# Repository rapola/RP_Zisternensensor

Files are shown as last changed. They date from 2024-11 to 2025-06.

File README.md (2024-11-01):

# RP_Zisternensensor
Wasser-Füllstandsensor für Zisternen
 * ## Hauptplatine für Auswertung und MQTT Sender
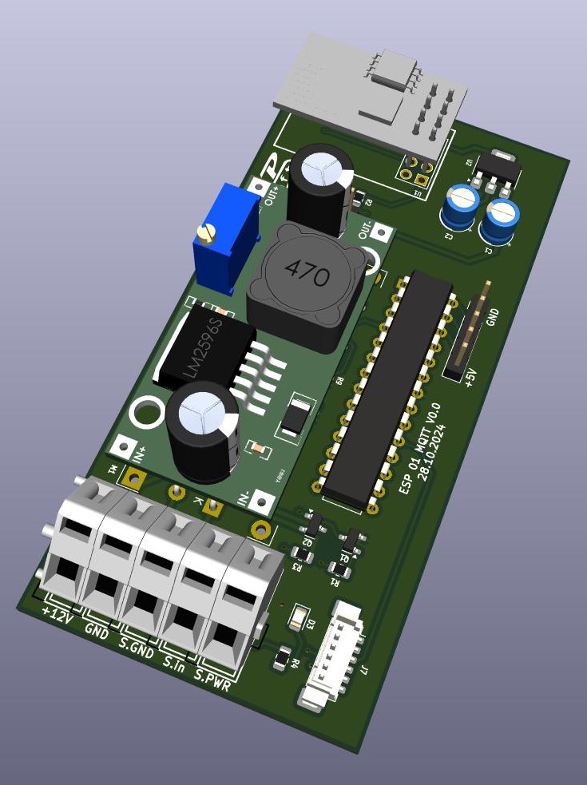
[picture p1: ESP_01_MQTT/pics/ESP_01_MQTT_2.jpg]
 
  <br>
  
  * ## Level Sensor:
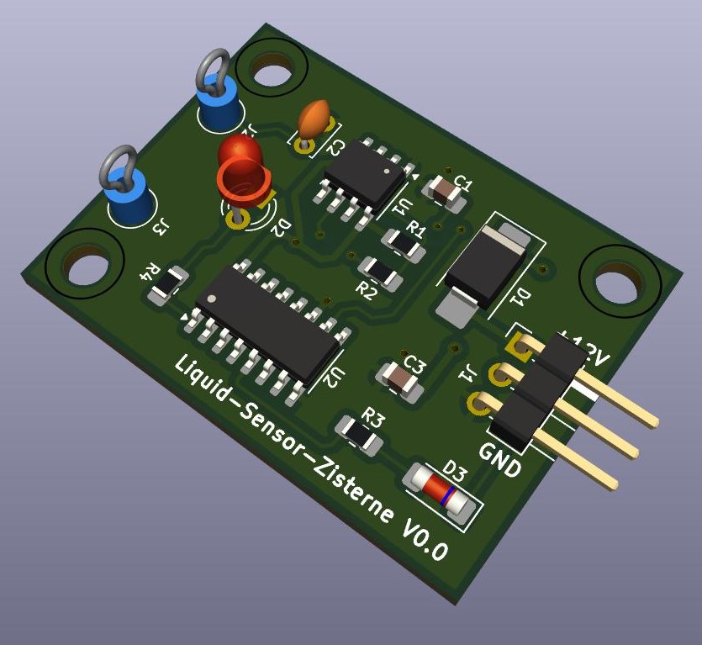
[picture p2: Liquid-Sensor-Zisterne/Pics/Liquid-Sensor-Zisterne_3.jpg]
  
  <br>

  ---
    
### Schematic

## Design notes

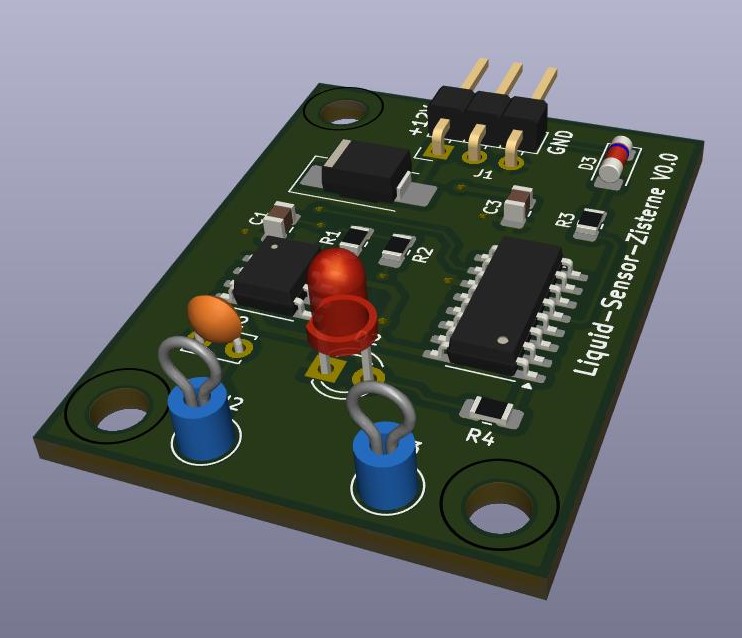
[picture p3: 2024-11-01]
Liquid-Sensor-Zisterne/Pics/Liquid-Sensor-Zisterne_2.jpg

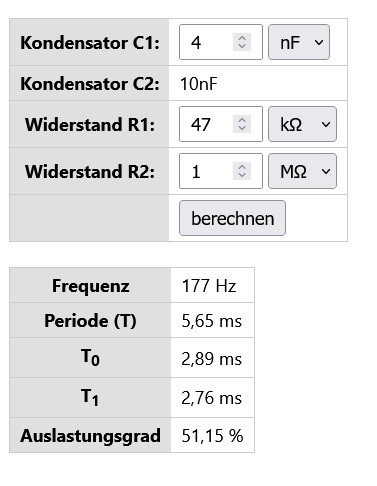
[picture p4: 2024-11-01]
Liquid-Sensor-Zisterne/Pics/NE555-4nf.jpg

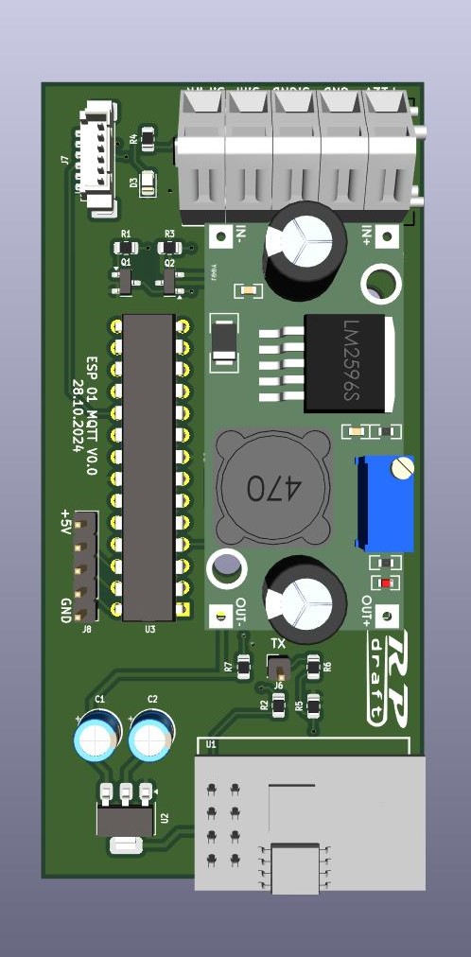
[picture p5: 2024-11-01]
ESP_01_MQTT/pics/ESP_01_MQTT_1.jpg

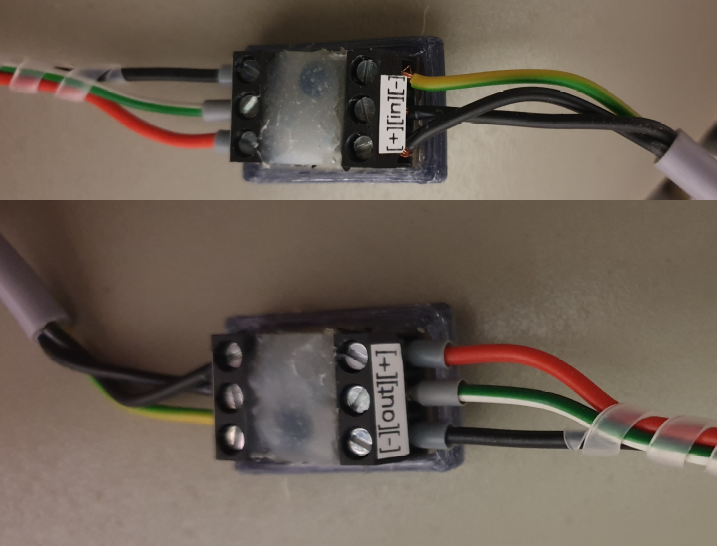
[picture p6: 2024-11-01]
Liquid-Sensor-Zisterne/Pics/Transistor-Stufe.png

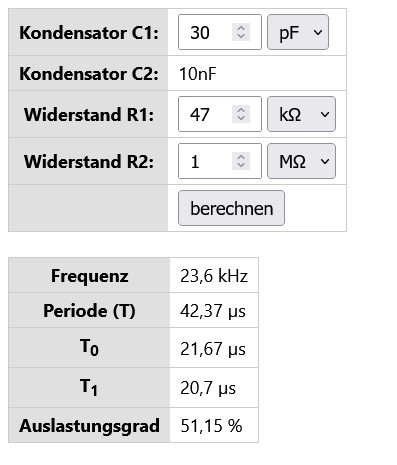
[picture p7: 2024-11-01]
Liquid-Sensor-Zisterne/Pics/NE555-30pf.jpg

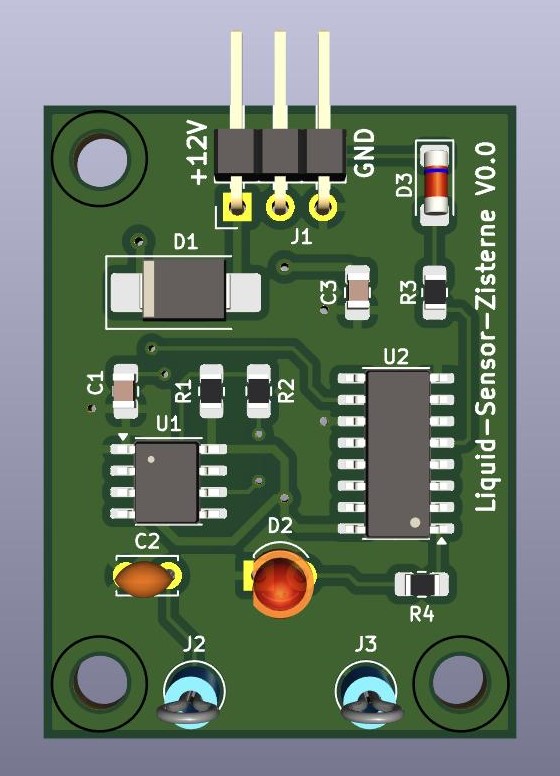
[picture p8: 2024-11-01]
Liquid-Sensor-Zisterne/Pics/Liquid-Sensor-Zisterne_1.jpg

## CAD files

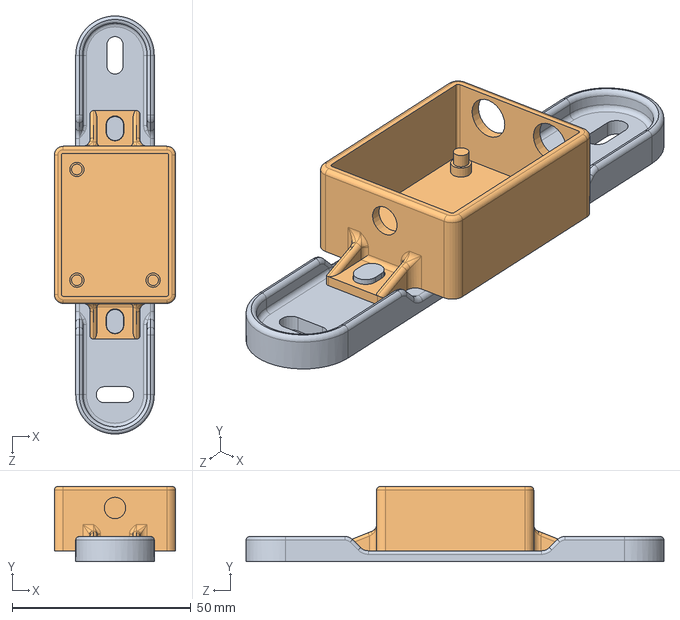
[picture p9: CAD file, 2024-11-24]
Liquid-Sensor-Zisterne/3D-Druck-Box/MBG-Sensor_01.SLDASM
34.0 x 21.0 x 117.0 mm
Vergussgeh_01
Adapter_95mm_Lochabstand

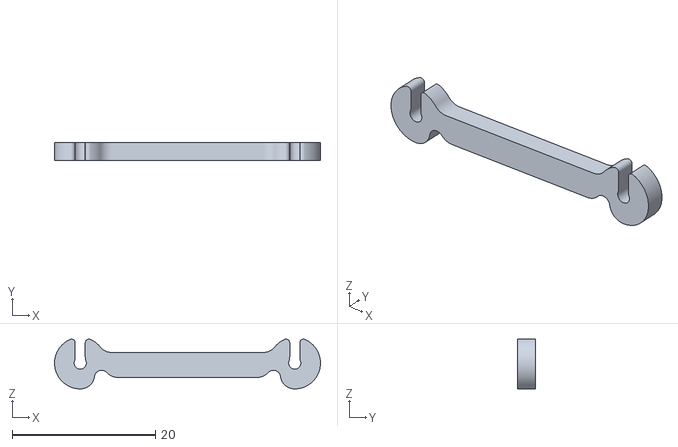
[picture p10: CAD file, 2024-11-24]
Liquid-Sensor-Zisterne/Abstandhalter_Kabel/Sensor-Abstandshalter_1.7-1.4-30.STL
37.2 x 2.50 x 6.96

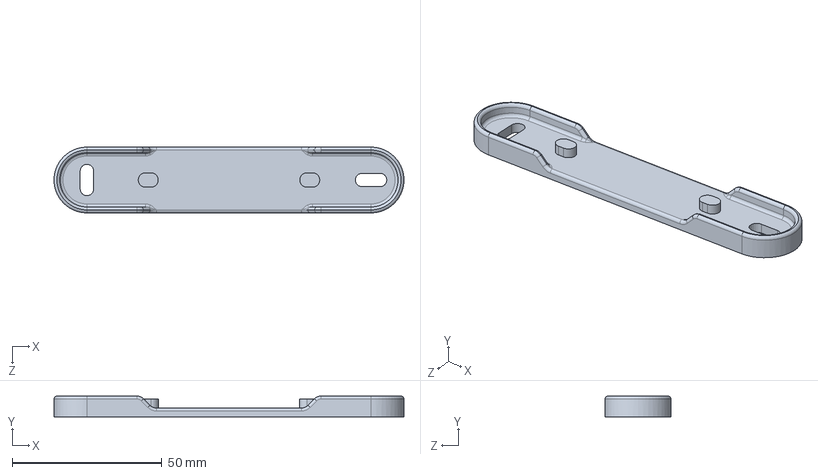
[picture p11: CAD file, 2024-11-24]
Liquid-Sensor-Zisterne/3D-Druck-Box/Adapter_95mm_Lochabstand.SLDPRT
117.0 x 7.00 x 22.0 mm

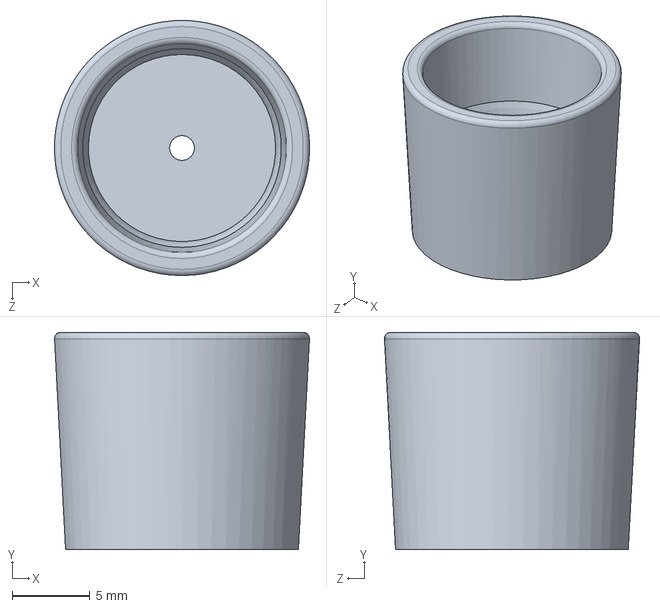
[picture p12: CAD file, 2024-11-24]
Liquid-Sensor-Zisterne/Abstandhalter_Kabel/Kabelende_Siegeltopf.SLDPRT
16.4 x 14.0 x 16.4 mm

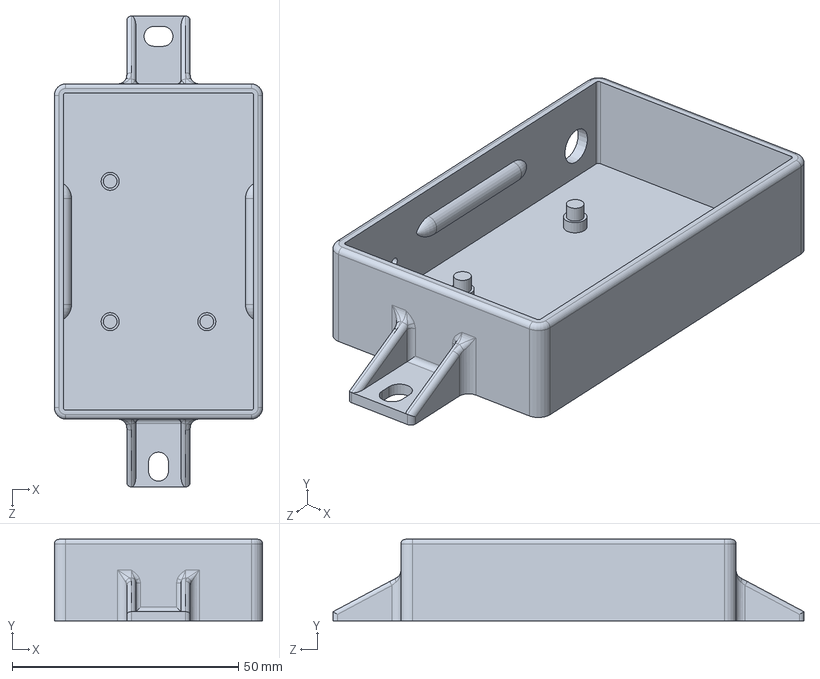
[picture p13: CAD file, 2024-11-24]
Liquid-Sensor-Zisterne/3D-Druck-Box/Vergussgeh_02.SLDPRT
46.0 x 18.0 x 104.0 mm

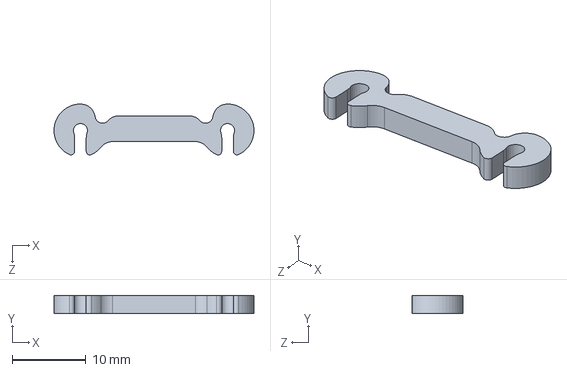
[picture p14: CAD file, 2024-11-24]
Liquid-Sensor-Zisterne/Abstandhalter_Kabel/Sensor-Abstandshalter.SLDPRT
27.2 x 2.50 x 6.92 mm

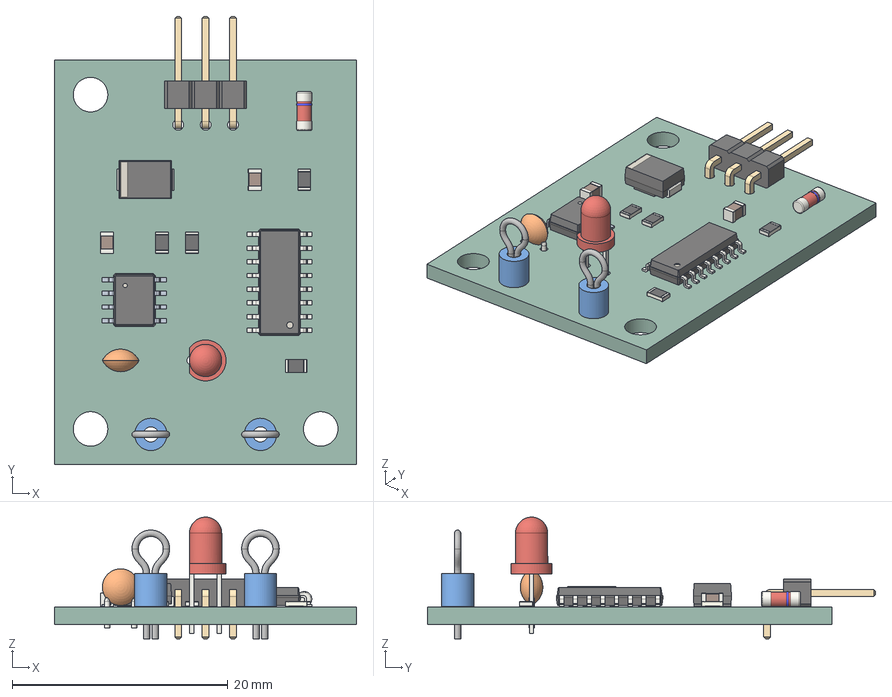
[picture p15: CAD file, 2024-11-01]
Liquid-Sensor-Zisterne/3D-Druck-Box/Liquid-Sensor-Zisterne.step
28.0 x 41.5 x 11.3 mm
R_0805_2012Metric x 4
D_MiniMELF_Standard
TestPoint_Loop_D3_50mm_Drill1_4mm_Beaded_cp x 2
C_0805_2012Metric x 2
D_SMB
PinHeader_1x03_P254mm_Horizontal
LED_D3.0mm
SOIC_16_39x99mm_P127mm
C_Disc_D34mm_W21mm_P250mm
CQ assembly
_autosave-Liquid-Sensor-Zisterne_PCB

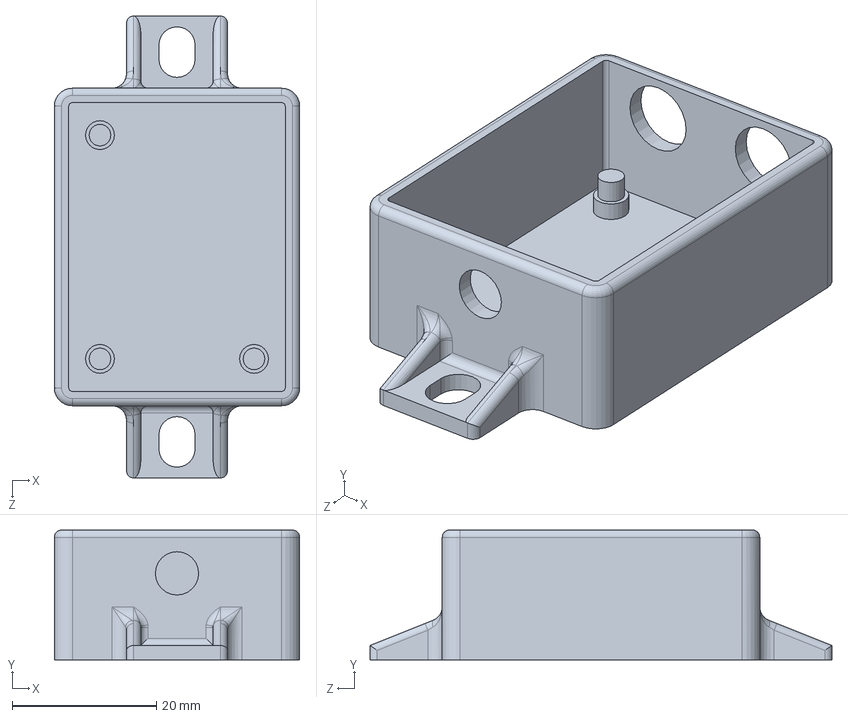
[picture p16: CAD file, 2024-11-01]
Liquid-Sensor-Zisterne/3D-Druck-Box/Vergussgeh_01.SLDPRT
34.0 x 18.0 x 64.0 mm

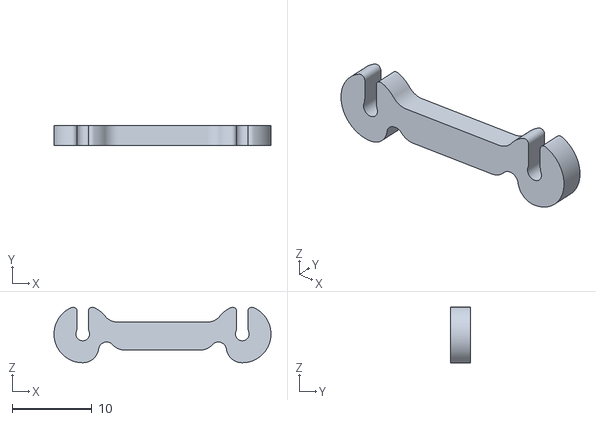
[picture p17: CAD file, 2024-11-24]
Liquid-Sensor-Zisterne/Abstandhalter_Kabel/Sensor-Abstandshalter_1.7-1.4-20.STL
27.2 x 2.50 x 6.96

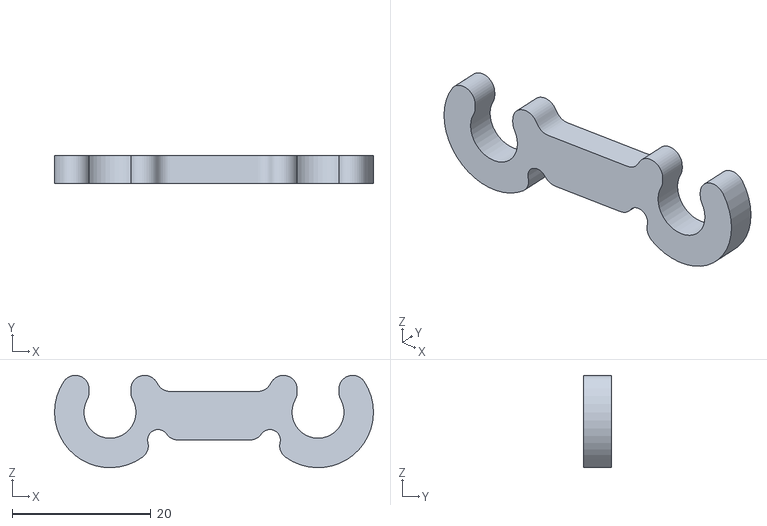
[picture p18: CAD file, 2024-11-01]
Liquid-Sensor-Zisterne/Abstandhalter_Kabel/Sensor-Abstandshalter_7.5-6-30.STL
46.0 x 4.00 x 13.3

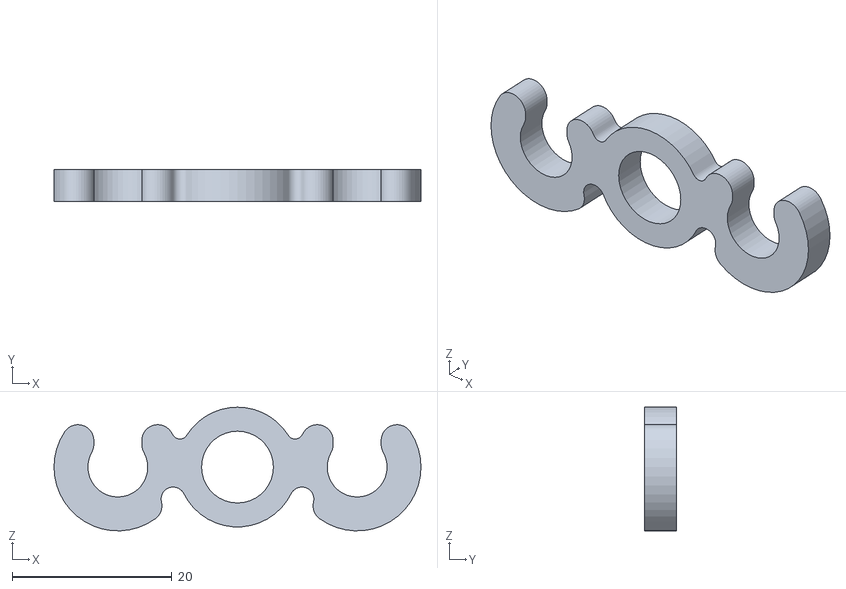
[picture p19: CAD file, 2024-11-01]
Liquid-Sensor-Zisterne/Abstandhalter_Kabel/Sensor-Abstandshalter_7.5-6-30_unten.STL
46.0 x 4.00 x 15.5

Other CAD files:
Liquid-Sensor-Zisterne/Abstandhalter_Kabel/Sensor-Abstandshalter_1.8-1.5-20.STL
Liquid-Sensor-Zisterne/3D-Druck-Box/Liquid-Sensor-Zisterne.SLDPRT
Liquid-Sensor-Zisterne/3D-Druck-Box/Vergussgeh_01.STL
Liquid-Sensor-Zisterne/Abstandhalter_Kabel/Kabelende_Siegeltopf.STL

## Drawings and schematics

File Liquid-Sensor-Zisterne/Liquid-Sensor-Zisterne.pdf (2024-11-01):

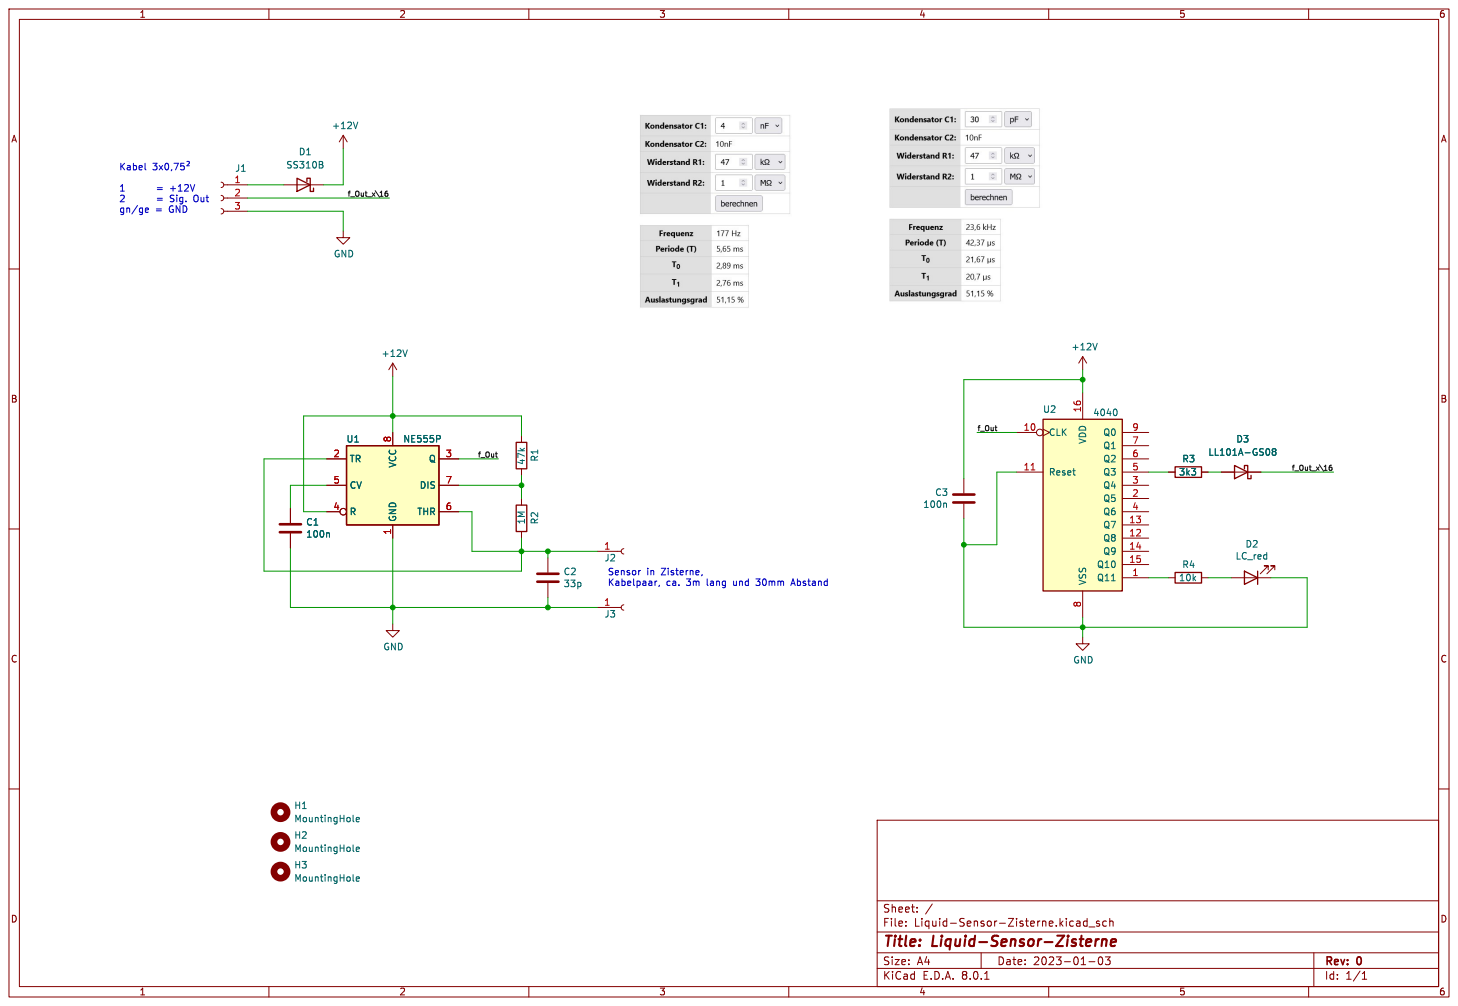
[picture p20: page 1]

File: Liquid-Sensor-Zisterne.kicad_sch Sheet: /
Id: 1/1 Title: Liquid-Sensor-Zisterne

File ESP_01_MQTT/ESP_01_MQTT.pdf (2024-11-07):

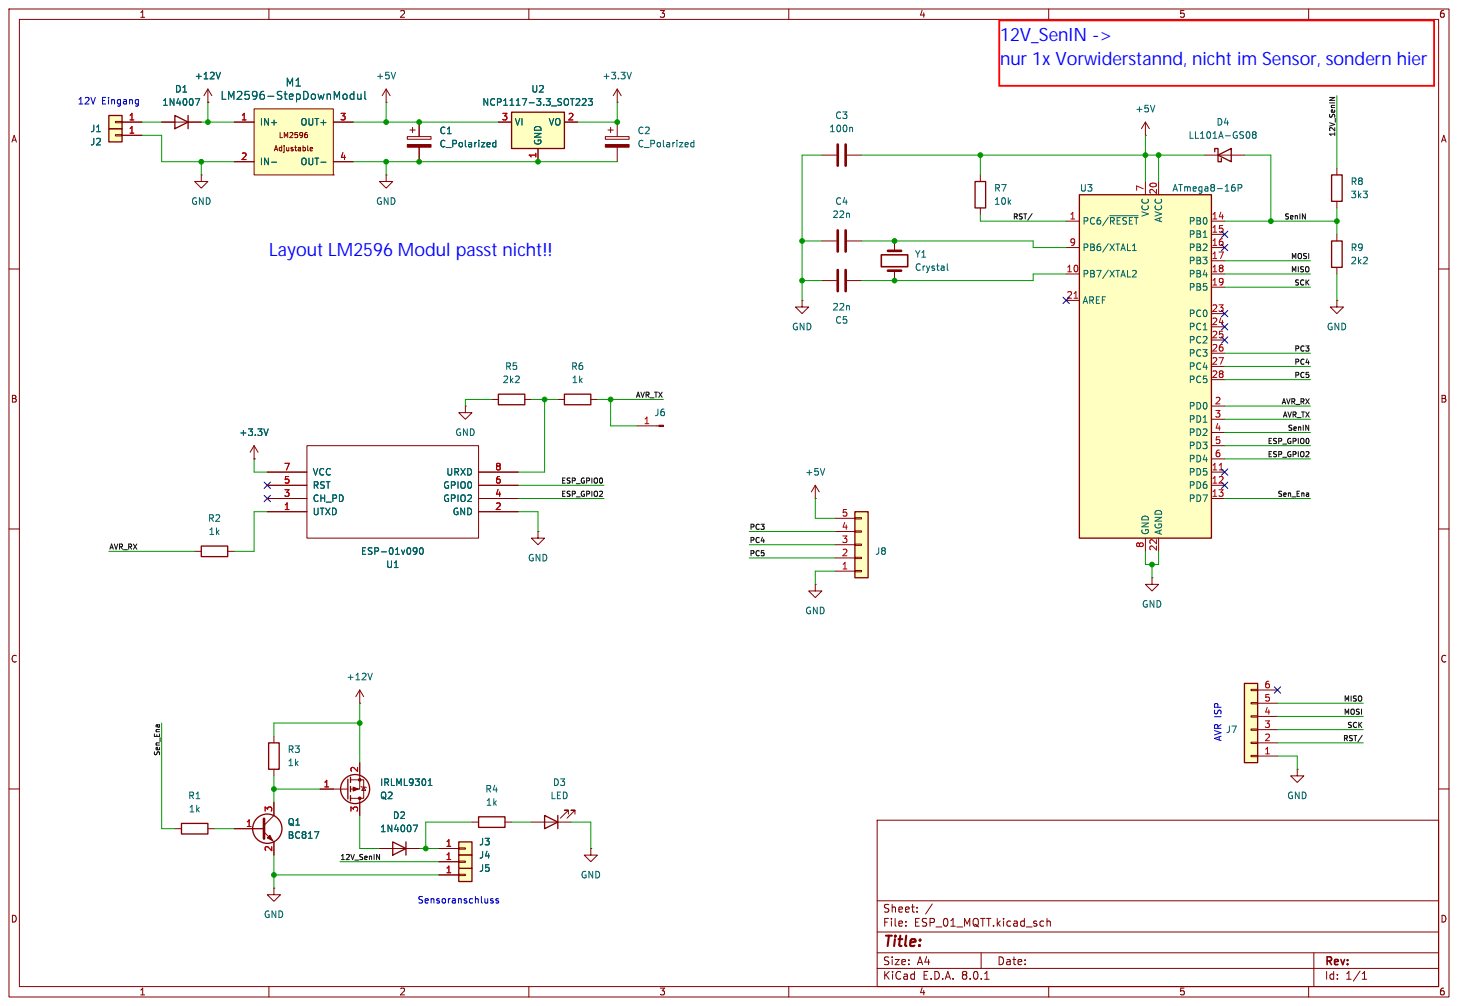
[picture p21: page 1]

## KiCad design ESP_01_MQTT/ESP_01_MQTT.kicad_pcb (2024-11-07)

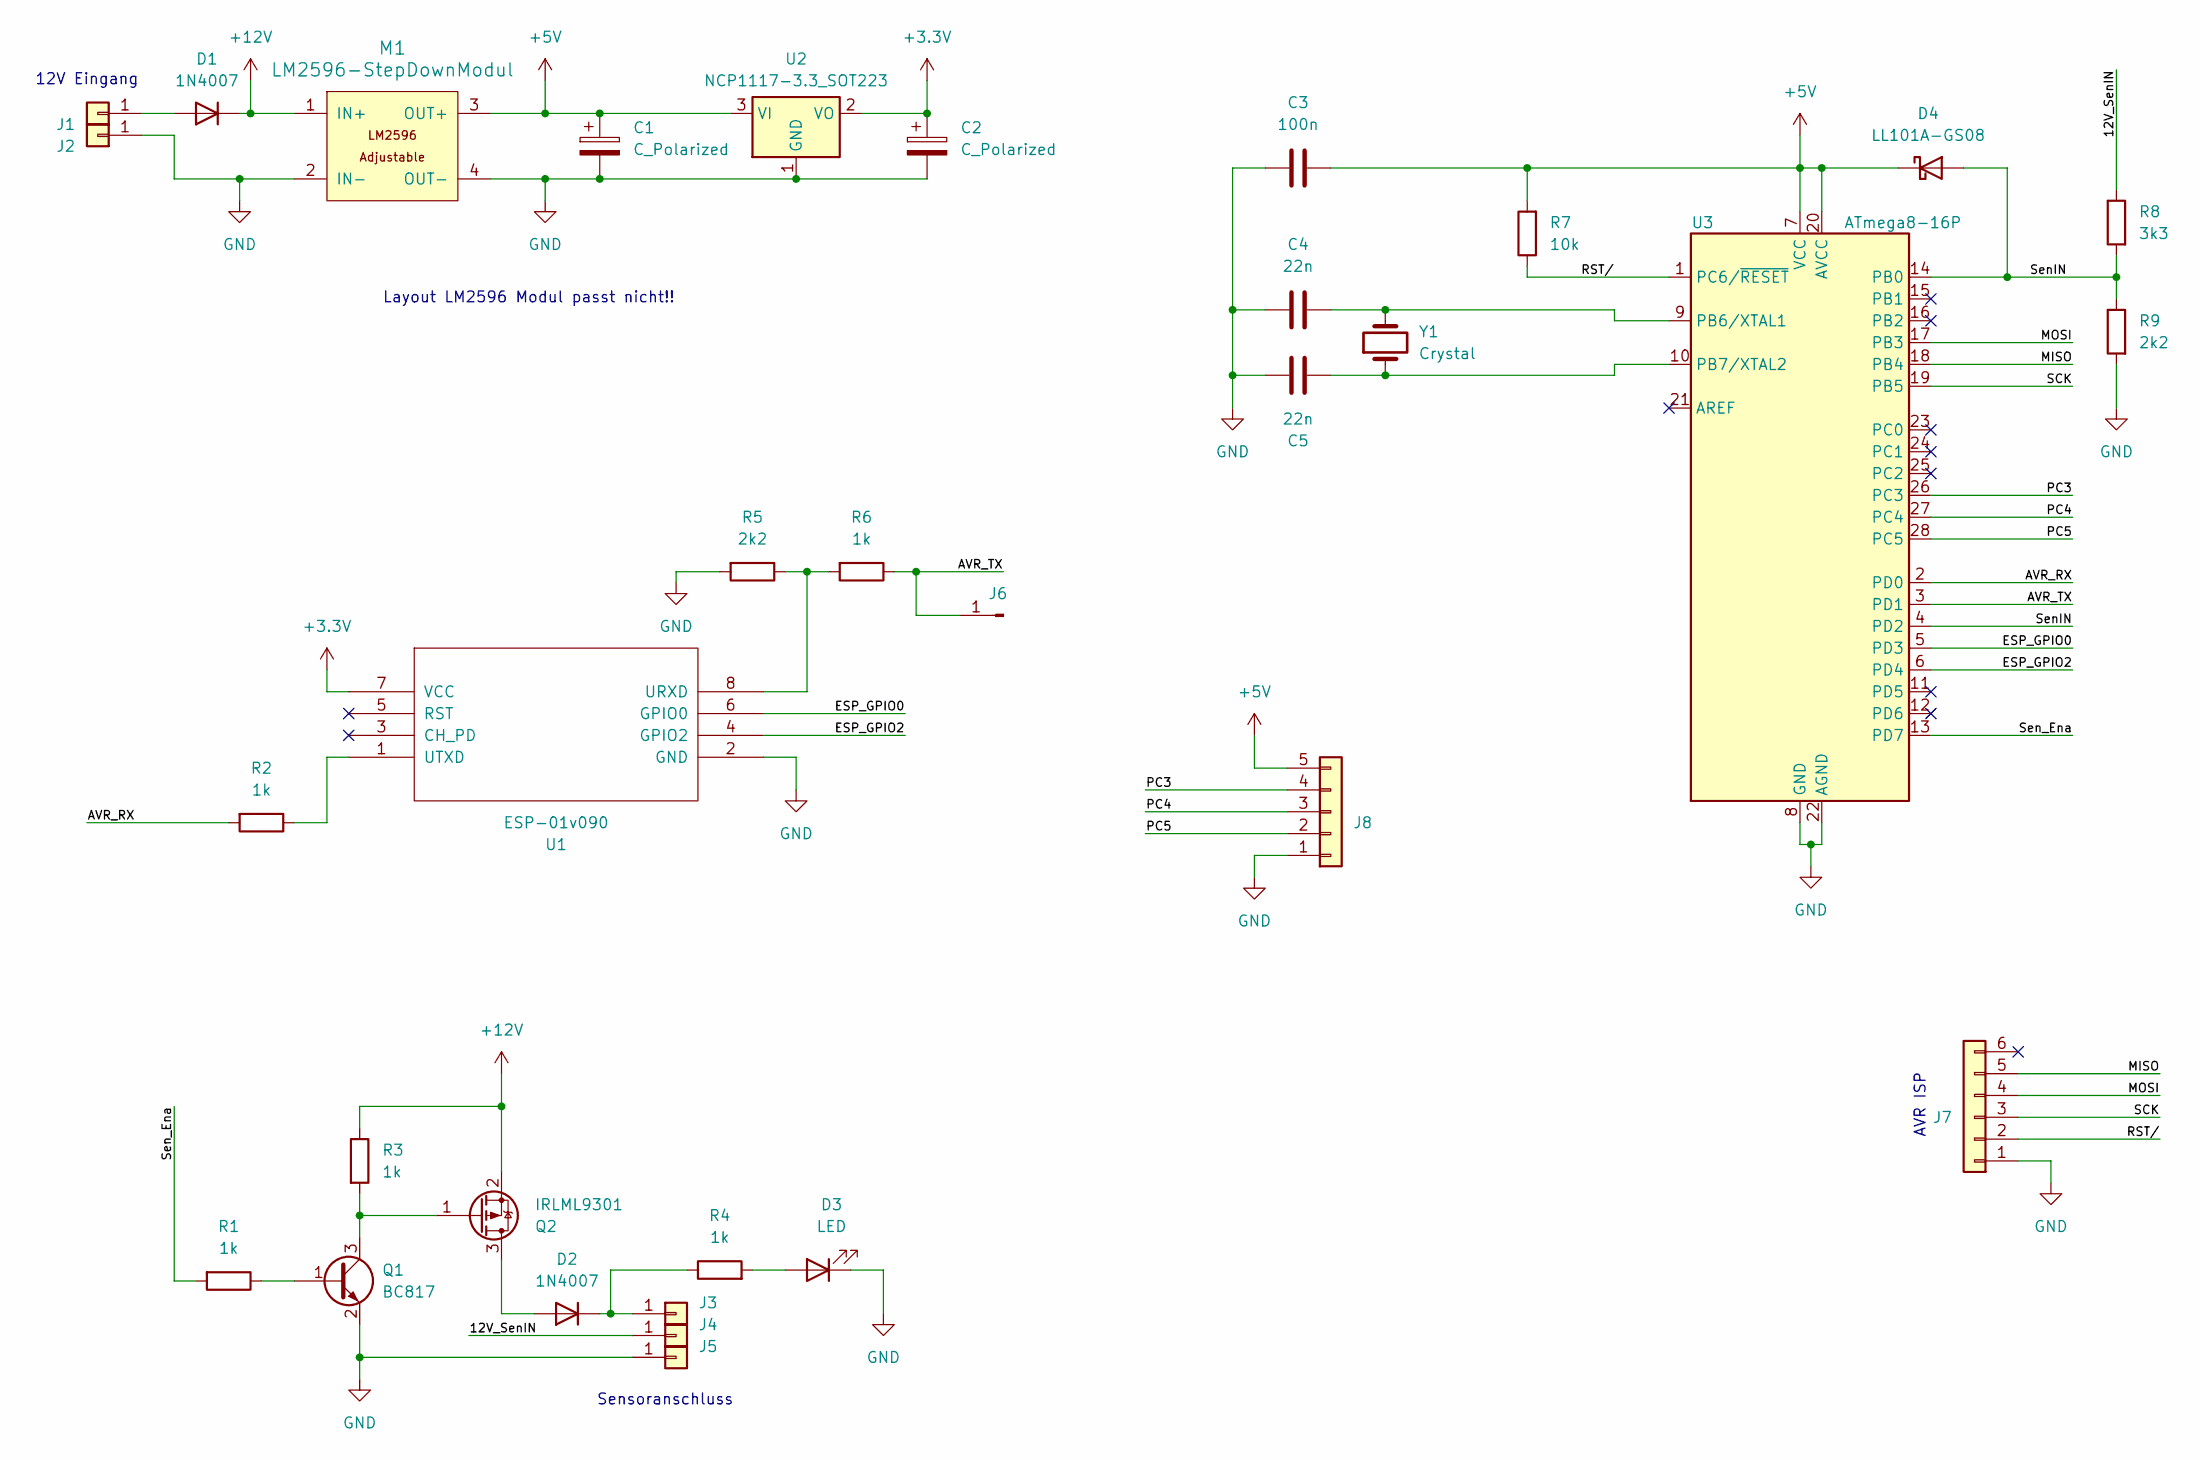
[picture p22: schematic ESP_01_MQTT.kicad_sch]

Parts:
C1, C2: C_Polarized; CP_Radial_D5.0mm_P2.00mm
C3: 100n; C_0805_2012Metric
C4, C5: 22n; C_0805_2012Metric
D1, D2: 1N4007; D_DO-41_SOD81_P10.16mm_Horizontal
D3: LED; LED_0805_2012Metric
D4: LL101A-GS08; D_MiniMELF
J1, J2, J3, J4, J5: Conn_01x01; Wago236-743_RM5
J6: Conn_01x01_Pin; PinHeader_1x01_P2.54mm_Vertical
J7: Conn_01x06; Molex_PicoBlade_53398-0671_1x06-1MP_P1.25mm_Vertical
J8: Conn_01x05; PinHeader_1x05_P2.54mm_Vertical
M1: LM2596-StepDownModul; YAAJ_DCDC_StepDown_LM2596_noSilk
Q1: BC817; SOT-23
Q2: IRLML9301; SOT-23
R1, R2, R3, R4, R6: 1k; R_0805_2012Metric
R5, R9: 2k2; R_0805_2012Metric
R7: 10k; R_0805_2012Metric
R8: 3k3; R_0805_2012Metric
U1: ESP-01v090; ESP-01
U2: NCP1117-3.3_SOT223; SOT-223-3_TabPin2
U3: ATmega8-16P; DIP-28_W7.62mm
Y1: Crystal; Crystal_HC49-4H_Vertical

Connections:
+3.3V: C2.1, U1.7 (VCC), U2.2 (VO)
+5V: C1.1, C3.2, D4.1 (K), J8.5, M1.3 (OUT+), R7.2, U2.3 (VI), U3.7 (VCC), U3.20 (AVCC)
+12V: D1.1 (K), M1.1 (IN+), Q2.2 (S), R3.1
/12V_SenIN: J4.1, R8.1
/AVR_RX: R2.2, U3.2 (PD0)
/AVR_TX: J6.1, R6.1, U3.3 (PD1)
/ESP_GPIO0: U1.6 (GPIO0), U3.5 (PD3)
/ESP_GPIO2: U1.4 (GPIO2), U3.6 (PD4)
/MISO: J7.5, U3.18 (PB4)
/MOSI: J7.4, U3.17 (PB3)
/PC3: J8.4, U3.26 (PC3)
/PC4: J8.3, U3.27 (PC4)
/PC5: J8.2, U3.28 (PC5)
/RST/: J7.2, R7.1, U3.1 (PC6/~RESET)
/SCK: J7.3, U3.19 (PB5)
/SenIN: D4.2 (A), R8.2, R9.1, U3.4 (PD2), U3.14 (PB0)
/Sen_Ena: R1.2, U3.13 (PD7)
GND: C1.2, C2.2, C3.1, C4.1, C5.1, D3.1 (K), J2.1, J5.1, J7.1, J8.1, M1.2 (IN-), M1.4 (OUT-), Q1.2 (E), R5.2, R9.2, U1.2 (GND), U2.1 (GND), U3.8 (GND), U3.22 (AGND)
unnamed: D1.2 (A), J1.1
unnamed: D2.2 (A), Q2.3 (D)
unnamed: D2.1 (K), J3.1, R4.1
unnamed: D3.2 (A), R4.2
unnamed: Q1.1 (B), R1.1
unnamed: Q1.3 (C), Q2.1 (G), R3.2
unnamed: R5.1, R6.2, U1.8 (URXD)
unnamed: R2.1, U1.1 (UTXD)
unnamed: C4.2, U3.9 (PB6/XTAL1), Y1.2
unnamed: C5.2, U3.10 (PB7/XTAL2), Y1.1

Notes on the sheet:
12V Eingang
Layout LM2596 Modul passt nicht!!
Sensoranschluss
AVR ISP

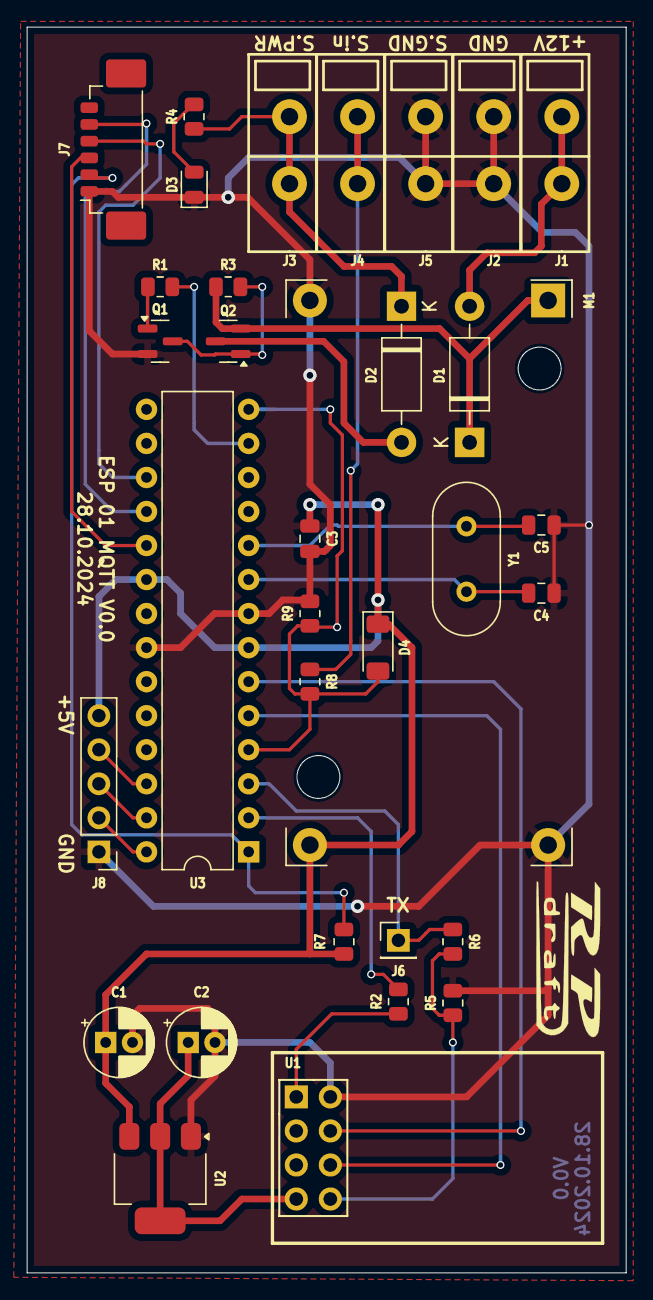
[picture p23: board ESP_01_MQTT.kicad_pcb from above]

Board: 2 copper layers, 44.7 x 93.0 mm, 33 parts (0 on the bottom side), 28 nets.

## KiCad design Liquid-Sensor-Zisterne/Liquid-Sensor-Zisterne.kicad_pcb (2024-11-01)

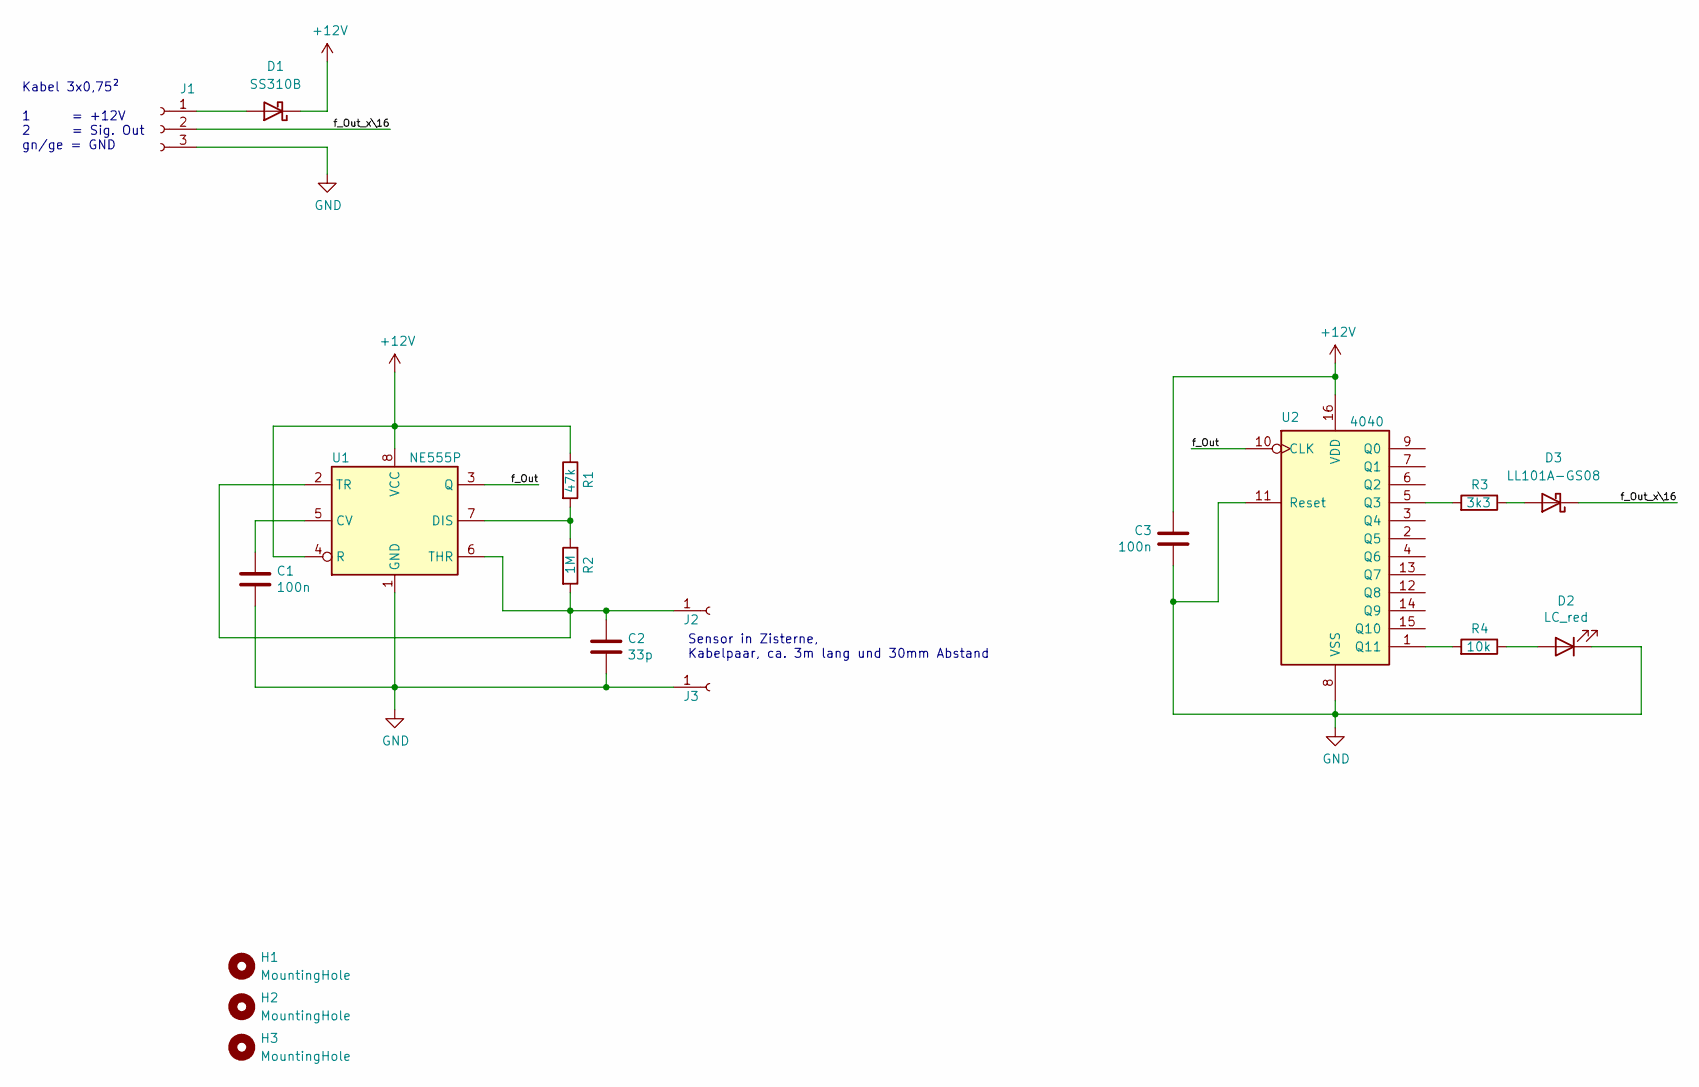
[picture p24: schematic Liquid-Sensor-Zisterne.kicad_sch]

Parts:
C1, C3: 100n; C_0805_2012Metric_Pad1.18x1.45mm_HandSolder
C2: 33p; C_Disc_D3.4mm_W2.1mm_P2.50mm
D1: SS310B; D_SMB_Handsoldering
D2: LC_red; LED_D3.0mm
D3: LL101A-GS08; D_MiniMELF
H1, H2, H3: MountingHole; MountingHole_3.2mm_M3_DIN965
J1: Conn_01x03_Female; PinHeader_1x03_P2.54mm_Horizontal
J2, J3: Conn_01x01_Female; TestPoint_Loop_D3.50mm_Drill1.4mm_Beaded
R1: 47k; R_0805_2012Metric_Pad1.20x1.40mm_HandSolder
R2: 1M; R_0805_2012Metric_Pad1.20x1.40mm_HandSolder
R3: 3k3; R_0805_2012Metric_Pad1.20x1.40mm_HandSolder
R4: 10k; R_0805_2012Metric_Pad1.20x1.40mm_HandSolder
U1: NE555P; SO-8_3.9x4.9mm_P1.27mm
U2: 4040; SOIC-16_3.9x9.9mm_P1.27mm

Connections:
+12V: C3.2, D1.1 (K), R1.1, U1.4 (R), U1.8 (VCC), U2.16 (VDD)
/f_Out: U1.3 (Q), U2.10 (CLK)
/f_Out_x\16: D3.1 (K), J1.2
GND: C1.2, C2.1, C3.1, D2.1 (K), J1.3, J3.1, U1.1 (GND), U2.8 (VSS), U2.11 (Reset)
unnamed: D1.2 (A), J1.1
unnamed: D2.2 (A), R4.1
unnamed: D3.2 (A), R3.1
unnamed: C2.2, J2.1, R2.2, U1.2 (TR), U1.6 (THR)
unnamed: C1.1, U1.5 (CV)
unnamed: R1.2, R2.1, U1.7 (DIS)
unnamed: R3.2, U2.5 (Q3)
unnamed: R4.2, U2.1 (Q11)

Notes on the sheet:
Sensor in Zisterne, Kabelpaar, ca. 3m lang und 30mm Abstand
Kabel 3x0,75² 1 = +12V 2 = Sig. Out gn/ge = GND

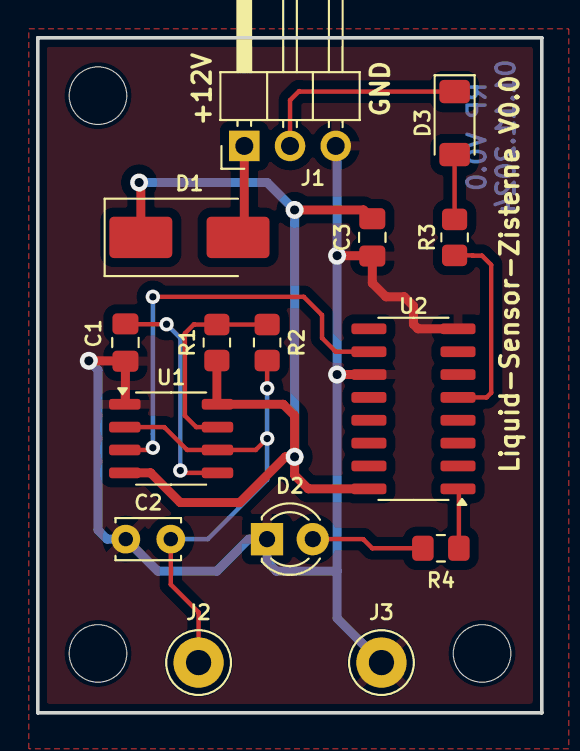
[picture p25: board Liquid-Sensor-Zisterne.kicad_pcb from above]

Board: 2 copper layers, 28.0 x 37.5 mm, 18 parts (0 on the bottom side), 12 nets.

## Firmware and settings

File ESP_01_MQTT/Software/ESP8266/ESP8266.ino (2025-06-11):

/*
Software für ESP-01 Füllstand Zisterne zu MQTT
Arduino 1.8.19
https://github.com/rapola/RP_Zisternensensor/blob/main/ESP_01_MQTT/Software

- mqtt beispiel
https://github.com/rapola/RP_HomeCAN/blob/main/Basis-Module/ESP-System/BASE-WEMOSminiD1_x92.V1/Software/WemosD1min-U1_Hackschn_V0.2/WemosD1min-U1_Hackschn_V0.2.ino
- publish Softwarversion every 2s
- listens to command "zisterne/cmd/get_freq", if payload "true" is received, send serial response to sensor (mega8) and wait for answer
- Serial answer from mega8 will be "ICP1val: xx123xx" (value or timeout message)
- publish "ICP1val:" on MQTT, topic "zisterne/freq"
- corresponding software: "Mega8", always use same Vx.x !!
*/

#include <ESP8266WiFi.h>
#include <ESPAsyncTCP.h>
#include <ESPAsyncWebServer.h>

#include "src/ElegantOTA_RP/AsyncElegantOTA_RP.h"         		//OTA

#include "src/RP_Arduino-SerialCommand/SerialCommand.h"	  		//Serial Command

#include "src/MQTT_RP/MQTT.h"

//-------------------------------------------------------
//global variables / constants
char SWVERSION[] = "ESP8266-V1.0";                  		      //current software version 
//const char* ssid = "KellerHorst";
//const char* password = "BIRP7913";

const char* ssid = "Taschner_HausNordOst";
const char* password = "birp7913-14042020";

const uint8_t Rdy_Pin        = 0;                             //GPIO0; set low to enable Mega8 connection

//---------------------------------------------------------------------
// create serial command object
SerialCommand sdata;

//---------------------------------------------------------------------
// MQTT
MQTTClient client;

const char* ip_of_mqtt_broker = "192.168.0.30";           		//mqtt borker ip, change to desired ip
const char* my_mqtt_clientID = "zisterne1";               		//unique, do not use name a second time in mqtt-mesh
const char* my_mqtt_username = "zisterne";                		//configured user in raspi mosquitto credentials
const char* my_mqtt_password = "zisterne";                		//configured password in raspi mosquitto credentials
const int mqtt_alive_time = 2;

const char* topic_lastWill      = "zisterne/offline";         //publish tested
const char* topic_swOwn         = "zisterne/swown";           //publish every 2s the Software Version
const char* topic_freq          = "zisterne/freq";        		//publish frequenz füllstand oder error
const char* topic_swOf_Mega8    = "zisterne/swsen";           //publish Software Version of Sensor (mega8)
const char* topic_cmd_get_freq  = "zisterne/cmd/get_freq";  	//subscribe to get freq
const char* topic_cmd_get_senSW = "zisterne/cmd/senSW";       //subscribe to get softwareversion of mega8

String cmd_true = "true";											                //if command is received, do something

//---------------------------------------------------------------------
// webserver
AsyncWebServer server(80);
WiFiClient net;

//####################################################################
void setup(void) {
  //-------------------------------------------------------
  // Pins
  pinMode(Rdy_Pin, OUTPUT);  
  
  Serial.begin(115200);
  //---------------------------------------------------------------------
  // setup callbacks for serial commands
  sdata.addCommand("#SW", SEND_SWVERSION);          			    //send software version
  sdata.addCommand("ICP1val:", READ_Serial_ICP1val);          //handle incomeing ICP1 values
  sdata.addCommand("ICP1err:", READ_Serial_ICP1err);          //handle incomeing ICP1 error
  sdata.addCommand("SW_Vers:", READ_Serial_SW);          		  //handle incomeing Softwareversion
  sdata.setDefaultHandler(unrecognized);            			    //handling of not matching commands, send what?
  delay(10);

  //---------------------------------------------------------------------
  // setup wifi
  IPAddress ip(192, 168, 0, 35);
  IPAddress dns(192, 168, 0, 1);
  IPAddress gateway(192, 168, 0, 1);
  IPAddress subnet(255, 255, 254, 0);
  
  WiFi.config(ip, dns, gateway, subnet);
  WiFi.mode(WIFI_STA);
  WiFi.begin(ssid, password);
  Serial.println("");

  // Wait for connection
  while (WiFi.status() != WL_CONNECTED) {
    delay(500);
    Serial.print(".");
  }
  Serial.println("");
  Serial.print("Connected to ");
  Serial.println(ssid);
  Serial.print("IP address: ");
  Serial.println(WiFi.localIP());

  //---------------------------------------------------------------------
  // setup OTA
  server.on("/", HTTP_GET, [](AsyncWebServerRequest *request) {
    request->send(200, "text/plain", "Hi! I am ESP8266, by Ralf.");
  });

  AsyncElegantOTA.begin(&server);    // Start ElegantOTA
  server.begin();
  Serial.println("HTTP server started");
  
  //---------------------------------------------------------------------
  // setup MQTT  
  client.begin(ip_of_mqtt_broker, net);
  client.onMessage(mqtt_messageReceived);
  mqtt_connect();
}

//####################################################################
void loop(void) {
  digitalWrite(Rdy_Pin, LOW);                                 //Enable Mega8
  
  //---------------------------------------------------------------------
  //call frequently to handle serial data communication
  sdata.readSerial(); 
  client.loop();    //MQTT
  delay(10);  // <- fixes some issues with WiFi stability
  
  if (!client.connected()) {
    mqtt_connect();
  }
  
  //---------------------------------------------------------------------
  // MQTT publish softwareversion
  static uint32_t last_ms;
  if(millis() - last_ms > 2000){
    last_ms = millis();
    MQTTpub_topic(topic_swOwn, SWVERSION);
  }

}

//### Serial #########################################################
//--------------------------------------------------------------------
//send software version
void SEND_SWVERSION() {
  Serial.printf ("SW: %s \r\n", SWVERSION);
}

//--------------------------------------------------------------------
//handle incomeing ICP1val, publish MQTT
void READ_Serial_ICP1val(){
  int hVal = 0;
  int lVal = 0;
  uint32_t Val = 0;
  char *arg;

  arg = sdata.next();
  if (arg != NULL) {
    hVal = atoi(arg);                                         // Converts a char string to an integer
  }

  arg = sdata.next();
  if (arg != NULL) {
    lVal = atol(arg);
  }

  Val = (hVal << 16 ) + lVal;
  String stringVal = String(Val);
  MQTTpub_topic(topic_freq, stringVal);                       // MQTT publish data
}

//--------------------------------------------------------------------
//handle incomeing ICP1err, publish MQTT
void READ_Serial_ICP1err(){
  char *arg;
  arg = sdata.next();                                         // Get the next argument from the SerialCommand object buffer
  if (arg != NULL) {                                          // As long as it existed, take it
    MQTTpub_topic(topic_freq, arg);                           // MQTT publish data
  }
}

//--------------------------------------------------------------------
//handle incomeing softwareversion, publish MQTT
void READ_Serial_SW(){
  char *arg;
  arg = sdata.next();                                         // Get the next argument from the SerialCommand object buffer
  if (arg != NULL) {                                          // As long as it existed, take it
    //Serial.printf("176 %s \r\n", arg);
    MQTTpub_topic(topic_swOf_Mega8, arg);                     // MQTT publish data
  } 
}

//-------------------------------------------------------------------
// non usable data received
void unrecognized(const char *command) {
  //Serial.println("What?");                                  //debug only
}

//### MQTT ###########################################################
//--------------------------------------------------------------------
//MQTT conntect, internal timeout in lib is 5s
void mqtt_connect(){
  client.setKeepAlive(mqtt_alive_time);
  client.setWill(topic_lastWill, my_mqtt_clientID);
  client.connect(my_mqtt_clientID, my_mqtt_username, my_mqtt_password);

  mqtt_subscribe(topic_cmd_get_freq);
  mqtt_subscribe(topic_cmd_get_senSW);
}

//--------------------------------------------------------------------
//MQTT subscribe to topic
void mqtt_subscribe(const char topic[]){
  client.subscribe(topic);
}

//--------------------------------------------------------------------
//MQTT publish topic
void MQTTpub_topic(const char topic[], String val){
  client.publish(topic, val);
}

//-------------------------------------------
//MQTT message empfangen
void mqtt_messageReceived(String &topic, String &payload){
  //Serial.println("incoming: " + topic + " - " + payload);   //uncomment for debug only!   
  if(topic == String(topic_cmd_get_freq)){
    if(payload == cmd_true){
      Serial.printf("GETF\r\n");                              //send serial command to get the value
    }      
  }
  else if(topic == String(topic_cmd_get_senSW)){
    if(payload == cmd_true){
      Serial.printf("#SW\r\n");                               //send serial command to get the softwareversion
    }      
  }
}

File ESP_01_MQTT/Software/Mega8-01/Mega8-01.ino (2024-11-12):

/*
Auswertung Freqeunzeingang
Arduino 1.8.19

AtMega8
PB0  AVR_ICP1          input from level-sensor
PD7  AVR_ENA_Sen12V    output, switch level-sensor on/off

- corresponding software: "ESP8266", always use same Vx.x !!
ToDo

*/

#include "src/RP_Arduino-SerialCommand/SerialCommand.h"	  		//Serial Command
#include <avr/interrupt.h> 

//-------------------------------------------------------
//global variables / constants
char SW_Vers[] = "Mega8-V1.0";

const uint8_t AVR_ICP1        = 8;                            //PB0;
const uint8_t AVR_ENA_Sen12V  = 7;                            //PD7;
const uint8_t PC_3            = 17;                           //not used, input pullup
const uint8_t PC_4            = 18;                           //not used, input pullup
const uint8_t PC_5            = 19;                           //not used, input pullup

const uint8_t AVR_ENA_Serial  = 3;                            //PD3; GPIO0 from ESP


struct tm{
  uint16_t capture_val;
  uint16_t ovf_val;
  uint16_t curr_capt_val;
  uint16_t curr_ovf_val;
};

volatile tm ICP;
uint32_t freq_timeout = 3000;                                 //3s timeout
uint8_t get_freq = 0;                                         //get ICP-val state machine
uint8_t rst_timeout = 0;                                      //for check if timeout has happend

//---------------------------------------------------------------------
// create serial command object
SerialCommand sdata;

//####################################################################
//--------------------------------------------------------------------
void setup() {
  delay(1000);
  Serial.begin(115200);
  //---------------------------------------------------------------------
  // setup callbacks for serial commands
  sdata.addCommand("#SW", SEND_SWVERSION);          			    //send software version
  sdata.addCommand("GETF", GET_FREQ);                         //set bit for getting and then sending ICP1_cnt
  sdata.setDefaultHandler(unrecognized);            			    //handling of not matching commands, send what?
  //Serial.printf("Software Version: %s \r\n", SW_Vers);
 
 //-------------------------------------------------------
  // Pins
  pinMode(AVR_ICP1, INPUT);
  pinMode(AVR_ENA_Serial, INPUT);
  pinMode(AVR_ENA_Sen12V, OUTPUT);
  pinMode(PC_3, INPUT_PULLUP);
  pinMode(PC_4, INPUT_PULLUP);
  pinMode(PC_5, INPUT_PULLUP);

  while(digitalRead(AVR_ENA_Serial) == HIGH){
    __asm__("nop\n\t");                                       //Do nothing
  }

 //-------------------------------------------------------
 // Timer
  noInterrupts();                                           //Timer 1 on, input capture Pin PB0 = ICP1 = 8
  TCCR1A = 0;
  TCCR1B = 0;
  TCCR1B |= (1 << ICNC1) | (1 << ICES1) | (1 << CS10);      //noise cancel, rising edge, clock/8
  //TIMSK1  |= (1 << ICIE1) | (1 << TOIE1);                   //Mega 328 input capture interrupt, overflow interrupt
  TIMSK  |= (1 << TICIE1) | (1 << TOIE1);                   //Mega 8 input capture interrupt, overflow interrupt
  interrupts();
  
}

//####################################################################
//--------------------------------------------------------------------
void loop() {
  //call frequently to handle serial data communication
  sdata.readSerial(); 

  if(get_freq == 1){
    digitalWrite(AVR_ENA_Sen12V, HIGH);                       //switch sensor on
    get_freq = 2;
    delay(2000);                                               //wait 300mS...
    rst_timeout = 1;
  }
  if(get_freq == 0){
    digitalWrite(AVR_ENA_Sen12V, LOW);                       //switch sensor off
  }
  
static uint32_t ms_start_measure;
if(get_freq == 2){
    ms_start_measure = millis();                              //timeout
    get_freq = 0;                                             //only once

    while((millis() - ms_start_measure) < freq_timeout){
      if(rst_timeout == 0){
        break;
      }
    }
 
    if(rst_timeout == 0){
      Serial.printf("ICP1val: %u %u\r\n", ICP.ovf_val, ICP.capture_val);
    }
    else{
      Serial.printf("ICP1err: Timeout\r\n");
    }
  }

}

//####################################################################
//--------------------------------------------------------------------
//TIM1 OVF 
ISR(TIMER1_OVF_vect){
  if(ICP.curr_ovf_val < 0xFFFF){
    ICP.curr_ovf_val ++;                                          // count overflows
  }
}

//-------------------------------------------------------
//TIM1 CAPT 
ISR(TIMER1_CAPT_vect){
  TCNT1 = TCNT1 - ICR1;                                       //new timer init, TimerCounter - inputCapture 
  ICP.curr_capt_val = ICR1;
  ICP.ovf_val = ICP.curr_ovf_val;
  ICP.capture_val = ICP.curr_capt_val;
  ICP.curr_ovf_val = 0;
  rst_timeout = 0;

}

//####################################################################
//--------------------------------------------------------------------
//send software version
void SEND_SWVERSION() {
  Serial.printf("SW_Vers: %s \r\n", SW_Vers);
}

//--------------------------------------------------------------------
//set bit for getting ICP1_cnt
void GET_FREQ(){
  get_freq = 1;
  //Serial.printf("Get_freq = %i \r\n", get_freq); 
}

//-------------------------------------------------------------------
// non usable data received
void unrecognized(const char *command) {
  //Serial.printf("What? \r\n");                              //Debug only
  __asm__("nop\n\t");                                         //Do nothing
}

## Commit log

2024-11-01 Projekt zusammengefasst
    [ESP_01_MQTT-B_Cu.gbr, ESP_01_MQTT-B_Mask.gbr, ESP_01_MQTT-B_Paste.gbr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]
2024-11-01 added Abstandshalter
    [Sensor-Abstandshalter.SLDPRT, Sensor-Abstandshalter_7.5-6-30.STL, Sensor-Abstandshalter_7.5-6-30_unten.STL]
2024-11-07 Hardware gelötet
    [ESP_01_MQTT.kicad_pcb, ESP_01_MQTT.kicad_sch]
2024-11-24 Alle Teile fertig, kurz vor Einbau
    [Adapter_95mm_Lochabstand.SLDPRT, Kabelende_Siegeltopf.SLDPRT, Kabelende_Siegeltopf.STL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]
